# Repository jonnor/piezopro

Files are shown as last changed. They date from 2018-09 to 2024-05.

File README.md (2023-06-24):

Piezo module with integrated preamp in fully shielded package.

# Status
Developing first prototype

# TODO

Preamp Revision 2 testing

* Measure frequency response of amplifier with Bitscope
* Measure signal/noise ratio or noise floor.
* Test with 5V power supply
* Test overvoltage on connector. VGND,HOT,COLD

Preamp Revision 3

* Depending on test results
* Test a charge amplifier?
* Test a JFET directly on piezo?

Final revision

* Document test procedure for PCB and/or assembly.

## Questions

* PCB stackup retains piezo sensitivity.
Put piezo onto PCB. With glue? Use adhesive tape to attach to instrument.
Measure output level. Compare to without PCB. Compare to coppertape+covertape.
Maybe the bottom should just be piezo+coppertape, sides+top is PCB? Can still look "perfect" from outside.
* PCB stackup is a good way to shield.
Test having just a few (4) connected holes in mid layer (from top/bottom). Can noise get in? 50Hz
Emulate side-plated PCB using copper tape. How much does it improve?
* Frequency response should include resonant peak.
For 27mm element is as low as 4kHz, within fundamentals of piano. 12mm=9kHz. 9mm=18kHz, edge of human hearing.
How pronouced is this peak actually when mounted on instrument?

# Design test

Revision 1. gain. 220k/22k. 10M input.
20mm Murata. Piezo in tin, glued. Lying on top of guitar. 
Measured GND, HOT. on output.
low E string. 80mVpp sustained, 500mVpp attack
G string. 70mVpp sustained, 700mVpp attack
high E string. 70mVpp sustain, 800mVpp attack

Current consumption 0.68 mA.

## Learnings

* Basic circuit works. Both with balanced and unbalanced inputs.
* Using a tin box works well as a shield.
* With microphone level input, signal is too hot.

# Worklog

Rev1: Circuit design verification. 22 hours

* Sept 08. 4 hours. Research exiting designs, initial schematic.
* Sept 09. 4 hours. Part selection and initial layout.
* Sept 09. 1 / 4 hours. Setup simulation in KiCAD.
* Sept 14. 1 hour. Sketching piezo mounts with rim/center attach
* Sept 19. 7 hours. Assembly and testing revision 1 PCB.
* Sept 22. 2 hours. Test overvoltage, calculate new component values

Rev2: Assembly concept verification. 7 hours 

* Oct 4. 4 hours. Update schematic and layout for revision 2. 
* Oct 8. 3 hours. Go through revision 2.
* Oct 3. 1 / 4 hours. Find out how to import artwork in KiCAD

Rev3: Production tweaked

* March 16. 2 hours. Make Python tool for vias shielding, use instead of edge platings

# Requirements

Electronics

* PCB is an enclosure for 20mm piezo. 25mm outer diameter
* BOM max 3 USD
* 100 hours++ on 9V battery. Max 2mA avg draw
* Low noise
* Balanced output. But also works with unbalanced inputs
* Line-level output, +4dBU
* 20Hz-20kHz bandwidth
* Reverse polarity protection
* Input overvoltage protection

Mechanics

* Cylindrical
* Fully shielded
* Output: 1/4" TRS female
* Power: 9V battery clip
* 1m cable, soft/flexible

# Sourcing

* Capacitors.
[0.1uF](https://no.farnell.com/w/c/passive-components/capacitors/ceramic-capacitors/smd-ceramic-multilayer-mlcc-capacitors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|35v&range=inc-in-stock-grp1&sort=P_PRICE)
[10uF](https://no.farnell.com/w/c/passive-components/capacitors/ceramic-capacitors/smd-ceramic-multilayer-mlcc-capacitors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|10v|25v|35v&range=inc-in-stock-grp1&sort=P_PRICE)
* NMOS. [BSS138L](https://no.farnell.com/on-semiconductor/bss138lt1g/mosfet-n-50v-0-2a-sot-23/dp/1431319)
* Diodes [SOD-532](https://no.farnell.com/w/c/semiconductors-discretes/diodes/small-signal-diodes?diode-case-style=sod-523|sod-523f&no-of-pins=2pins|3pins&packaging=cuttape&range=inc-in-stock-grp1|exc-obs&sort=P_PRICE)
*  Zeners [SOD-523](https://no.farnell.com/w/c/semiconductors-discretes/diodes/zener-single-diodes?zener-voltage-vz-typ=3.3v|3.6v|3.9v|4.3v|4.7v|5.1v&diode-case-style=sod-523|sod-523f&no-of-pins=2pins|3pins&packaging=cuttape&range=inc-in-stock&sort=P_PRICE)
* Opamp. [TL062](https://no.farnell.com/search/prl/results?packaging=cuttape&range=inc-in-stock&st=tl062&sort=P_PRICE)
* Piezo [Farnell](https://no.farnell.com/w/c/sensors-transducers/transducers/sensing-transducers/piezo-transducer-elements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|35mm&range=inc-in-stock)

# BOM

[Octopart BOM](https://octopart.com/bom-tool/TbIQ2Cbo/OKDwL97yteywY4BA)

## Testing

Testing aspects

* PCB design verification
* Enclosure/mount design verification
* Production checks.

Tough-but-normal conditions

* 3-8 microphones
* Plugged into standard mixer with 50m cable
* 1 9V battery per microphone

Reverse polarity:
Hold battery on wrong way for 10 seconds, plug right way, ensure works OK.

Overvoltage:
Hit piezo with hammer. Ensure performance good afterwards.

Frequency response:
Connect signal generator at PCB input, with capacitor simulating piezo capacitance.
Sweep sinewave, record output, calculate frequency response.

Noise.
Internal noise. No signal. Measure output
Injected noise/interference (on output line, at microphone).
Attempt to inject 50Hz by wire. Lightbubl+dimmer.
Measure without shielding, and with.

## References

Electronics

* [Elliot Sound Products: Balanced Line Driver](http://sound.whsites.net/articles/dwopa3.htm#s10)
* [Elliot Sound Products: High-Z ](http://sound.whsites.net/articles/high-z.html)
* [WikiPedia: Line level](https://en.wikipedia.org/wiki/Line_level). Consumer: -10dBV 0.894 Vpp, Pro: +4dBu 3.472
* [StackExchange.com: Piezo FET preamp balanced output](https://sound.stackexchange.com/questions/687/diy-contact-microphone/37714#37714).
Developed by Alex Rice, www.zachpoff.com/diy-resources/alex-rice-piezo-preamplifier/.
Extremely simple design. Used as base for DIY kits and complete microphone Cortado MkII from Zeppelin Labs. 
* [Elliot Sound Products: Piezo Pickup Preamplifiers](https://sound-au.com/project202.htm).
Tested high-Z preamp versus Charge Amplifier.
First opamp stage is charge amp with 1x gain, then second stage sets desired gain.
Found that high-Z would pick up (50hz) hum, where as charge amplifier did not. When piezo was connected with bare leads.
Tested with TL072 and found it very quiet.

Shielding

* [Shielding fabric](https://www.aliexpress.com/item/Emf-shielding-Fabric-Signal-Block-Fabric-Military-Nickel-Fabric/32795159060.html)
* [Shielding paint](https://www.stewmac.com/Pickups_and_Electronics/Shielding/Conductive_Shielding_Paint.html)

Simulation

* [ngspice: Using KiCAD as GUI](http://ngspice.sourceforge.net/ngspice-eeschema.html)
* [eCircuitCenter: Basic SPICE opamp model](http://www.ecircuitcenter.com/Circuits/opmodel1/opmodel2.htm)
* [WikiPedia: Piezoelectric sensor](https://en.wikipedia.org/wiki/Piezoelectric_sensor).
Basic model (disregards resonance): Voltage source with a capacitor in series.

## Existing products

Active contact microphones

- Schertler. [Thommann](https://www.thomann.de/gb/schertler_dyn_uni_p48_contact_microphone.htm).
48V phantom power.
310 EUR.
- Cortado MkII [from Zeppelin Labs](https://zeppelindesignlabs.com/product/cortado-mkiii-contact-microphone/).
48V phantom power. Two gain settings, low-frequency cutoff switch.
150 USD assembled.
- K&K Pure pickup plus K&K Pure preamp. [Thommann](https://www.thomannmusic.no/kk_pure_preamp.htm?sid=fd268c89787f256dcc79b210d18a3667).
Total around 300 EUR

# Usage ideas

* Guitar. Acoustic, electric, traveller.
* DIY Cigarbox
* CNC mill an electric travel guitar from single piece of wood. Rosewood/maple.
https://www.aliexpress.com/item/Hot-Sale-Custom-Electric-Travel-Guitar-Portable-Style-Rosewood-Fretboard-22-Frets-with-Soft-Bag-can/32803999609.html
* Violin,viola,chello. 
* Double bass. 
* Stomp box

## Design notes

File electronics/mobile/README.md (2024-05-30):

# PiezoPro Mobile preamp

Designed for use with consumer electronics like mobile phone / PC.
And an off-the-shelf piezo module. Either from music store, China online, or using own piezo disc.

# Features

- 3.5 mm input jack for piezo
- 3.5 mm output jack. Line level
- Adjustable gain. 0 to 34 dB?
- Ability to switch on/off
- Rechargable battery. 100 hours + battery life
- USB-C charging port
- Shielded chassis

# Implementation

- Li-ion battery. Cell on JST style connector.
- CMOS opamp
- 3d-print casing. Copper tape for shielding?

# Background

## Opamp choice

CMOS opamps seems to be the way to go.
High impedance. Low power. Low noise. Good gain bandwidth product.

- TI OPA1671. 900 uA consumption
- TI OPA314. 150 uA consumption

## Battery types
Lithium polymer on JST connector.

- 602025, 200 mAh.
- 502035, 400 mAh

On-PCB.

- LIR2450, 100 mAh.

## References

### Metal Marshmellow Pro

Metal marshmellow Pro has 0-34 dB gain.
Has phantom power.

### Metal Marshmellow II

https://metalmarshmallow.com/MM_II.php

Has an internal battery. 10 days battery life. 240 hours.
Charging via micro USB. Charging time 1 hour.
Fixed gain. Multiple variants. From 0 to +34 dB. With +24 dB considered "normal" gain.
Seems to use a standard 20 ish mm piezo disc as the input element.

Says +14 dB is good for loud percussion.
And +24 dB for normal.
And +33 dB for very quiet sounds.

### Metal Marshmellow DIY

Can here see the circuit that is being used in the Pro.

Seems to be a single opamp. Markings are 1D3 ?
According to TI part lookup this could be OPA1671, a CMOS 

With 3-5.5 V range.
With input protection diodes etc.
DC output as well as AC coupled.
Can connect a pot-meter to pins, or fixed SMD resistor to set gain.

### Stompville

https://stompville.co.uk/cart/preamps

Seems to be based on a discrete JFET.
Has +14 dB gain.

Multiple versions. Unbalanced output PCB. Phantom power PCB.
Fully enclosed, alu chassis.

Prices around 50 GPD for PCB.

###

https://www.instructables.com/Hi-Z-Opamp-Piezo-Buffer/

P48 phantom power design, with balanced output.
OPA1642 based.
Has the schematic.
Modern SMD circuit board also available.
https://www.jlielectronics.com/diy-accessories/p48-hi-z-piezo-buffer/ - 35 USD.
Nice standard case in steel with XLR/6.35mm for keeping it in.

### JFET composite amplifier

JFE150 has a complete reference design for a JFET composite amplifier (JFET + single opamp).
With gain up to 60 dB.
Well described, in terms of component choices.

However, a standard CMOS/JFET opamp is probably good enough?
The JFE150 part is a bit exotic.

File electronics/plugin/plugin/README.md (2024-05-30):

# Plug-in-power

Contains a single JFET buffer, designed to be powered from "Plug in power" (PIP) at 3-5 volts.
Very similar to off-the-shelf electret microphone modules are done.
Can be directly plugged into a device with mic-level input supporting PIP.
Such as a portable recorder, PC, phone or laptop.
Or use preamps or adapters designed for electret microphones.

Board designed to be soldered directly to piezo element, using castellated edge holes.
The assembly should then protected mechanically using silicone etc,
and be shielded completely using copper tape.
And potentially coated with plastidip et.c. to be fully waterproof.
Output is a NN cm long cable with 3.5 mm TRRS male.

## TODO

- Adapt circuit to have trimpot for Rs
- Select and order components. Follow Zack Hoff PIP amp. JFET: 2SK209
- Make and test initial circuit
- Measure gain, noise levels

## Open questions

- Does this two-step amplified design work give good quality? First JFET buffer, then external preamp?
Test the circuit externally.
Test how copper shielding affects.
Over just the piezo. Over piezo, and PCB separate. Over piezo and PCB integrated.

- How is sound pickup influenced by mounting PCB onto the piezo?

Alternative fully-integrated design.
Put everything needed also for P48V phantom power and 9V.
Then just have different sets of wires coming out for different connectivity options.

## Challenges

Multiple usage scenarios with different expectations of connection

- Instrument. 9V battery + female jack
- XLR with phantom power
- Portable recorder. Plug-in-power. Though some also have XLR or TRS

Different usage scenarious may have different input level,
and require different gain

- Ambient listening. High sensitivity desired
- Stringed/plucked instruments. Guitar, kaliba, piano etc. Relatively loud
- Percussive instruments. Very loud / high energy

## Learnings

### Direct soldering

06.08.2023. Tested soldering a PCB board with castellated holes directly to a PCB.
Worked quite nicely. Heated the PCB castellated first, then feed solder on pad, then towards piezo.
Used 280 deg C soldering iron, was sufficient.

## Components

#### SMD JFET for audio

SOT23 DSG: Gate on tip

- 2SK3557 - SOT23 DSG
- MMBF4416A - SOT23 DSG
- MMBF5484/MMBF5485/MMBF5486 - SOT23 DSG. 5484 has lowest VGS_off - good
- MMBFJ309/MMBFJ310 - SOT23 DSG. 309 has lowest VGS_off - good
- MMBF4393LT1G - SOT23 DSG
- MMBFJ201 - SOT23 DSG.
- SST201 - SOT23. Low cutoff voltage
- LSBF510 - SOT23. Low cutoff voltage
- 2N4117

Very expensive

- sst310

Discontinued

- MMBF4393
- Philips bf512
- MMBF4416
- BF256B
- BF862
- BF556

Specialiy

- JFE150 SOT23-5. Modern. Includes clamping diodes

Electret Capsule Microphone (ECM) specialized

- 2SK208. SOT23. Pin order different? No proction diodes. Normally in stock Digikey.
- 2SK1109. SOT23. Comes with binning of IDDS. Obsolete? 
- TF256TH. One diode internally. Comes with binning of IDDS. SC-106A SMD. Obsolete?
- NTE2917. TO92S

Others by others with success

- 2SK209. By Zack Hoff

## References

### Zack Poff: PIP Stereo Piezo Preamplifier

https://www.zachpoff.com/resources/pip-stereo-piezo-preamplifier/

Very simple circuit.
JFET, Zeners for protection.
Mentions possibility of adding a capacitor on Rs to increase gain.
Used the 2SK209 SMD JFET (IDSS grade Y). After testing many others.
Zeners are back-to-back. 5.1V
Stereo. Two channels on single PCB.
Have to solder inputs and outputs to wires. No connectors.
3d-printed enclosure.
Has a "pad" switch. Pulls some capacitors to ground.
Says there is sufficient gain for quiet sources. But not the best for percussive. Presumably overloading output.

!! He has tested the spread of the JFETs.
They should be measured and binned by IDSS, for best results.

Excellent starting point for an inline PIP preamp.
Would instead use 3.5 mm female jacks. SMT, avoid soldering cable.
Also tweaking the enclosure and PCB to make shielding trivial. 
Copper foil/tape that connects to PCB. Solder one spot and then press-connect.
And order it pre-made at JLCPCB etc.

His preamp was used in combination with below DYI piezos.

### 3D-Printed DIY Contact Microphone

https://www.zachpoff.com/resources/3d-printed-diy-contact-microphone/
27mm piezo disk.
Glued to 1-1/8″ dia Aluminum discs. Approx 29 mm.
3D-printed back shells.
The alu disc makes them quite sturdy. Also also reduces the reasonant peak. At the expense of some sensitivity.
?? No shielding in the enclosure. Not mentioned the effect of this.
Tested by students over many years.

Seems like a very practical construction.

### Elliot Sound: JFET amplifier design
https://sound-au.com/articles/jfet-design.htm#s3

Most important JFET parameters:

- the gate-source cutoff voltage VGS (off). Aka  'pinch-off' voltage (VP).
- and the maximum current with zero gate voltage (IDSS).

Must in practice be measured.
Large amount of unit variation in these. 
Shows a practical test circuits to measure the key parameters.

Lots of discussion on how to set bias point (via selecting R_s).
Recommends a trim-pot for R_s.

The lower the supply voltage, the more accurate the biasing needs to be.

## Bias point and component selection

In this applicaion there will also be some external variation in R_s on,
so the circuit must be robust to a reasonable range of these.
Complicates testing of the bias point. 

In practice JFET selection is likely to be critical.
And it is quite likely that JFETs must be measured/binned.

=> this design is only ideal when direct operation as "elecret" mic is needed.
If an external power source is acceptable, then a op-amp based charge amplifier is better.

Gain adjustment has to be primarily done by selecting another JFET.
The other option is to use the resistive divider on the input,
but this reduces SNR. 

## Accessories

#### XLR converter

PIP 3.5mm TRS to XLR phantom power

- Rode VXLR+
https://www.thomann.de/be/rode_vxlr_416774.htm
- Movo FXLR-PRO 
- Boya 35C-XLR

#### Battery box

Ideally with jack socket (female).
For guitar amp etc connection.

Not so much completely ready??

- MC-401 condenser mic mixer. 4 in, 1 out
- MC33202 Dynamic Condenser Microphone Preamplifier. 1 elecret input 
- Soundman A3 adapter?
- Soundprofessionsals SP-SPSB-1
https://soundprofessionals.com/product-category/microphone-power-modules-battery-modules/

There are a bunch of ready-made electret amplifier boards

- 3V/5V/12V Input MAX9812 Electret Microphone Amplifier
- LM358

Would need to add minijack input, jack output, and 9V battery connector.

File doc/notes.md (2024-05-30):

Make into piezo preamplifier board.
Allowing use of any piezo.
Source some decent piezo elements that is tested together.
Provide as a kit.

Externals. Connectors etc

- Piezo input. 3.5 mm audio jack
- Audio output. 3.5 mm audio jack.
- Power. 5.5 mm DC jack
- Gain. 2/3 way switchable button
- LED power indicator
- Power switch?

Accessories:

- 3.5 mm jack to XLR 
- DC jack to 9V battery
- 3.5 mm stereo extension cord

Physical characteristics

- Like an 9V battery. 50 mm x 30 mm x 15
- In-line connections.
Input connector on one side, output connectors other side
- Preferably a way to attach with screws?

DC 5.5 OD socket is 11 mm tall above PCB. Min 15mm tall
3.5 mm audio jack is 12m diameter
DC 5.5 OD jack is 10 mm diameter

PP3 size battery is 48.5 mm × 26.5 mm × 17.5 mm
XLR connector is 70 mm x 19 mm diameter

## Audio connector
https://www.digikey.com/en/products/filter/barrel-audio-connectors/434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

## Power connector
https://www.digikey.com/en/products/filter/barrel-power-connectors/435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

## Switches
https://www.digikey.com/en/products/filter/slide-switches/213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

# Existing

Guitar piezo/ceramic preamp/amplifiers

## EQ-7545R

Approx 7 USD from China
Belcat branded 25 USD
4 band EQ and volume control.
For building into guitar
9V battery holder
2.5mm female socket internal for piezo input
6.35 mm female socket for audio output

https://www.gear4music.no/no/Gitar-and-Bass/Belcat-EQ-7545-4-bands-Aktiv-Preamp/AV8

## Radial Stagebug SB-4
DI box for piezo
1000 NOK
48 V phantom power
https://www.gear4music.no/no/PA-DJ-and-belysning/Radial-StageBug-SB-4-Active-Piezo-DI-Box/V6S

Provides full specifications
Tilsvarende inngangsstøy: -101dBu
Støy gulv: -97dBu 

## Casing

Light enough to work with double sided tape
Optional mounting bracket

Can easily become the most expensive part
Should be rugged enough to have good price
Stock plastic with cutouts?
Aluminum (or plastic) profile with custom sides

https://www.hammfg.com/electronics/small-case/extruded/1455
might be hard to find small enough
want ideally 5 mm tall

G2AA DIY Aluminum Case Electronic Project PCB Instrument Box 45x45x18.5mm
23x44x60mm PCB Junction Box Metal Aluminum Cooling Box DIY

3d-printed?
Could one use texturing etc to make it look good?

https://www.romanreiner.com/creating-textures-for-3d-printing/
Texturing using displacement map
https://grabcad.com/tutorials/how-to-3d-texture-your-parts-for-fdm-printing-using-solidworks-2019
https://www.cati.com/blog/2019/06/how-to-quickly-add-texture-to-fdm-3d-prints-in-solidworks/
Triangular
Bowtie
Can be done in Blender?

If the part is small and flat enough, maybe just a sticker on top will make it look OK

Can one make the price good

## Usecases

- Drums/percussion
- Guitar. Acoustic/electric
- Violin

## Output

Ready to be used with

- Guitar amplifier
"instrument level"
Like an Active DI box.
- Phone/tablet/computer
Using the microphone input
Will need a 9V battery
- XLR audio interface
Either a mixer or USB audio soundcard
"mic level"

## Distributors

- Thomann
- Gear4music

## Configuration

- Power input source
Between phantom and 
Maybe auto-switch instead?
Prefer phantom power where present

- Gain / output level.
Some instruments might be very loud
Some piezos might be very loud
Continiously adjustable. Potmeter
Or couple of steps. 10,20db pad

- High pass filter
Need to avoid handling noise etc
Can be a lot of energy in the low-end
Maybe a switchable filter
Generally better to use an EQ

- Low pass filter
Not so important where it is
Better to use an EQ

# Testing method

## Real-world test
Place on some instrument.
Compare with other piezos.

On acoustic guitar.

## Measurements wrt reference

Need a reference equipment with known response.
Either linear or just well specified

Probably not so important in practice

## Main characteristics

- Signal to Noise ratio
Higher signal level usually beneficial.
Since there is also input noise
- Frequency response
Want low freq dropoff to avoid/reduce handling noise
High dropoff outside hearable range
- Distortion

- Softstart. No pop on power on/off

## Piezo resonance

Piezos have natural resonances.
Depends primarily on size of element
The height of peak proably also depends on material around piezo, and how it is mounted
Some manufacturers specify it
Might

# References

## Line levels

https://www.plaiddogrecording.com/lesson-2

Line-level. Balanced or unbalanced compatible.

    Microphone Level = -58 dBu to +2.2 dBu = 1 millivolt to 1 volt
    Instrument Level = -17.7 dBu to +7 dBu = .1 volt to 1.736 volts
    Line Level = -4.8 dBu to +4 dBu = .447 volts to 1.228 volts
    Speaker Level = +7 dBu to +30 dBu and above = 1.736 volts to 24.5+ volts

While the values for these levels can vary and overlap quite a bit, the average levels (references) are around here:

    Mic Level = -30 dBu = 24 mV
    Instrument Level = 0 dBu = .775 V
    Line Level = +4 dBu = 1.228 V
    Speaker Level = +14.26 dBu = 4 V

Instrument level and line level nearly the same.
Mic level considerably different.

Can typical XLR mic preamps handle instrument or line level?

Behringer Xenix. Max level +10 dBu, yes

## Piezo levels

What are the levels the piezo produces under the range of usecases?

NOTE: may depend the buffer being used.
Baseline: JFET unity-gain opamp

Instrument usage

- Guitar. Electric vs acoustic. Soft vs hard playing. High vs low strings.
- Kalimba. Soft vs hard playing
- Drums. Electronic pad
- Piano.

Sound installation

- Bridge with someone walking on it
 Or just the

Overload conditions

- Drop piezo on floor
- Hit with finger
- Hit with hammer

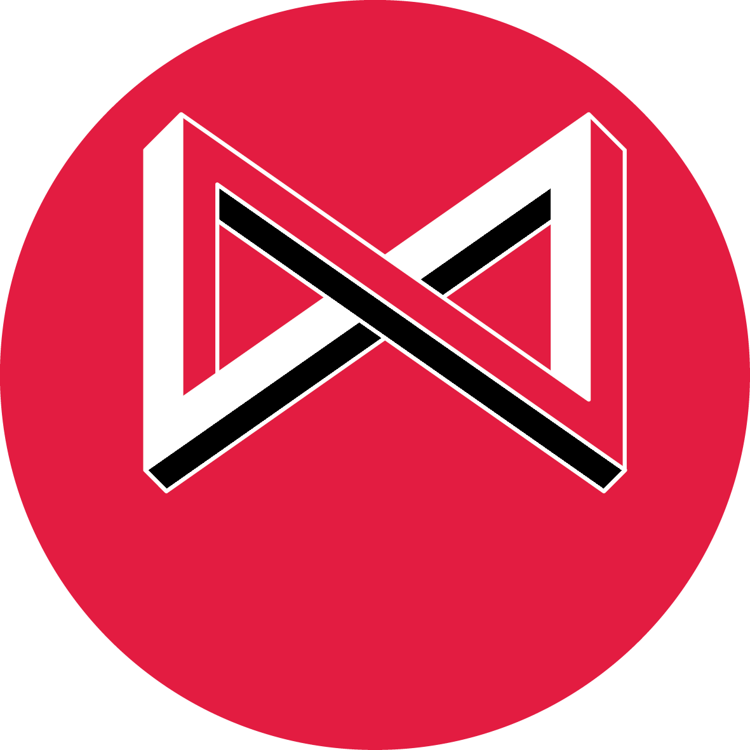
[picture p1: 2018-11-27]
electronics/preamp/artwork-midres-contrast.png

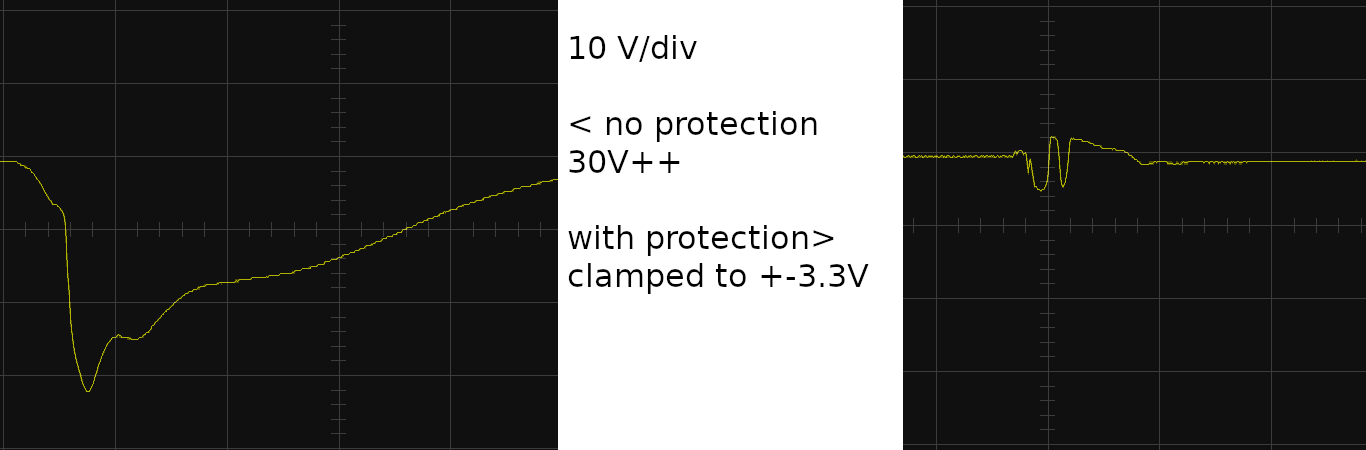
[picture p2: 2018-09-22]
doc/img/overvolt-protect-murata-20.png

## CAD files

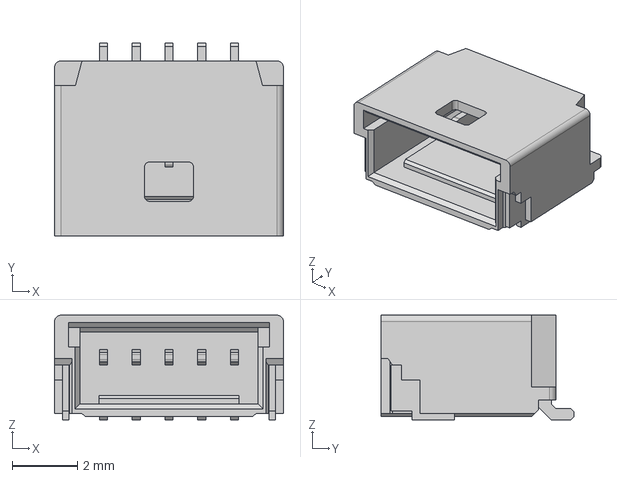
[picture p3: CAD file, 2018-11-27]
electronics/MOLEX Pico-Clasp 5-xy.step
7.00 x 5.90 x 3.20 mm

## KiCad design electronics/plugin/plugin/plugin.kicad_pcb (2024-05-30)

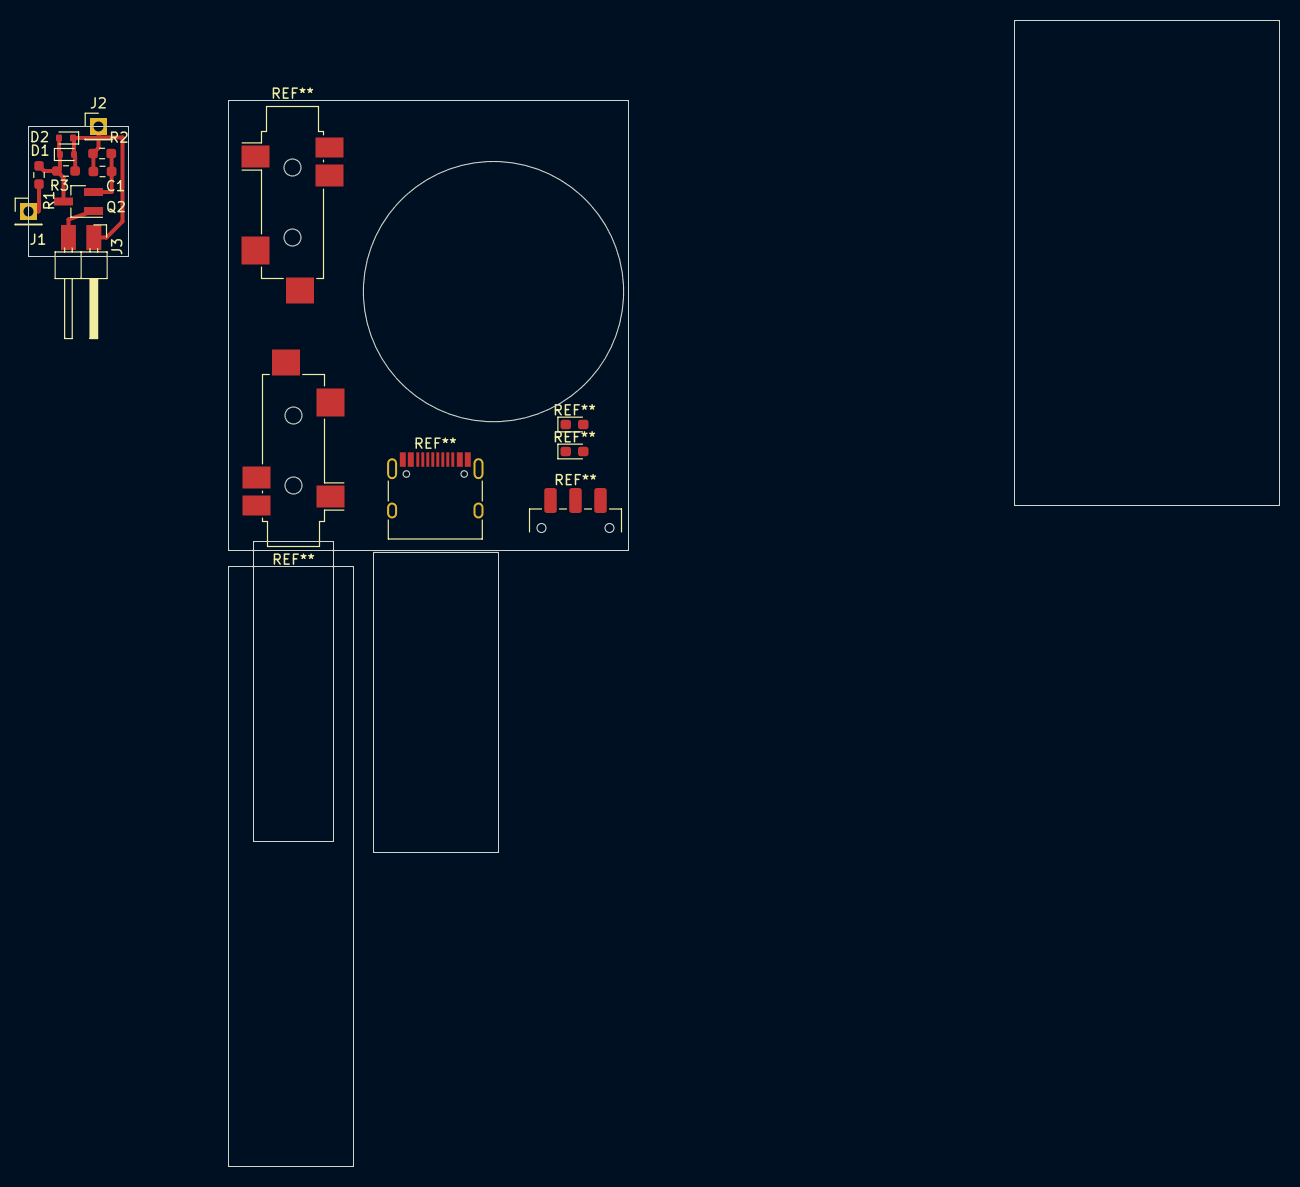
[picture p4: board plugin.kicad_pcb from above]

Board: 2 copper layers, 125.1 x 114.6 mm, 10 parts (0 on the bottom side), 5 nets.

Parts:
C1: C; R_0603_1608Metric_Pad0.98x0.95mm_HandSolder
D1, D2: D; D_SOD-523
J1, J2: Conn_01x01; PinHeader_1x01_P2.54mm_Vertical
J3: Conn_01x02; PinHeader_1x02_P2.54mm_Horizontal
Q2: Q_NMOS_DSG; SOT-23_Handsoldering
R1: 100; R_0603_1608Metric_Pad0.98x0.95mm_HandSolder
R2: R; R_0603_1608Metric_Pad0.98x0.95mm_HandSolder
R3: 1M; R_0603_1608Metric_Pad0.98x0.95mm_HandSolder

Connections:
/GATE: D1.1 (K), D2.2 (A), Q2.3 (G), R1.2, R3.1
/OUT: J3.2, Q2.1 (D)
GND: C1.2, D1.2 (A), D2.1 (K), J2.1, J3.1, R2.2, R3.2
unnamed: J1.1, R1.1
unnamed: C1.1, Q2.2 (S), R2.1

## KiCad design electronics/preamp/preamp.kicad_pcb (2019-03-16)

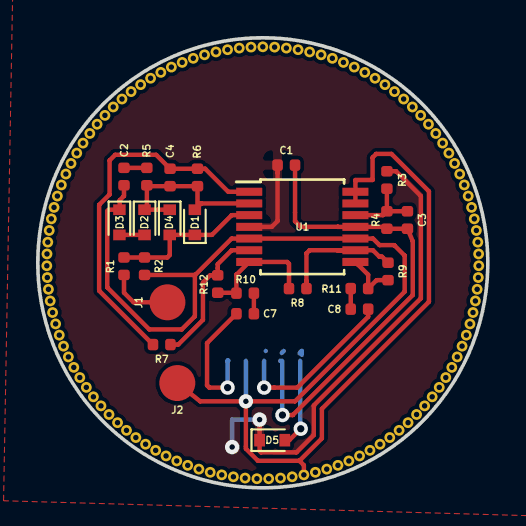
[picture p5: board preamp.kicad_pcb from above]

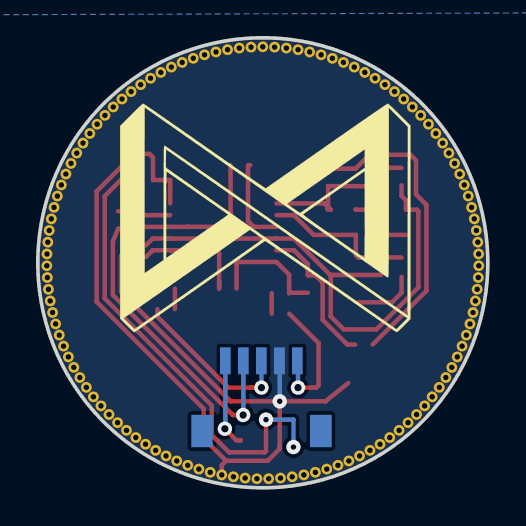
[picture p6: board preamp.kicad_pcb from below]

Board: 2 copper layers, 25.0 x 25.0 mm, 28 parts (2 on the bottom side), 19 nets.

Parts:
C1, C3: 0.1uF 15V; C_0402_1005Metric
C2: 1uF; C_0402_1005Metric
C4: 1000pF; C_0402_1005Metric
C7, C8: 10uF; C_0402_1005Metric
D1, D4, D5: D; D_SOD-523
D2, D3: Zener 3V1; D_SOD-523
J1, J2: Conn_01x01; TestPoint_THTPad_1.0x1.0mm_Drill0.5mm
J3: Conn_01x05; Molex_Pico-Clasp_202396-0507_1x05-1MP_P1.00mm_Horizontal_No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
J4: Conn_01x01; viashield
R1, R3, R4, R5, R6, R7: 12k; R_0402_1005Metric
R2: 10M; R_0402_1005Metric
R8, R9: 100k 1%; R_0402_1005Metric
R10, R11: 100 1%; R_0402_1005Metric
R12: 27k; R_0402_1005Metric
U1: TL064; TSSOP-14_4.4x5mm_P0.65mm

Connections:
+BATT: D5.2, J3.1
-BATT: C1.2, C3.2, J3.2, R4.2, U1.11
/AMP: C4.2, R6.1, R7.2, U1.1
/BUF+: R8.2, R10.2, R12.1, U1.7
/BUF-: R9.1, R11.2, U1.8
/GAIN-: R7.1, R12.2, U1.6
/IN+: J1.1, R1.2
/INV-: R8.1, R9.2, U1.9
/OUT+: C7.1, J3.5
/OUT-: C8.1, J3.3
/PRE+: D1.1, D4.2, R1.1, R2.2, U1.3
/PRE-: C4.1, D1.2, D2.1, D4.1, R5.2, R6.2, U1.2
/VGNDREF: C3.1, R3.2, R4.1, U1.12
unnamed: C2.1, R5.1
unnamed: C7.2, R10.1
unnamed: C8.2, R11.1
unnamed: D2.2, D3.2
VCC: C1.1, D5.1, R3.1, U1.4
VGND: C2.2, D3.1, J2.1, J3.4, J4.1, R2.1, U1.5, U1.10, U1.13, U1.14

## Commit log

2018-09-08 Initial schematic
    [preamp.kicad_pcb, preamp.sch]
2018-09-09 Add reverse polarity protect
    [preamp.sch]
2018-09-09 Output caps, fix opamp annotations
    [preamp.sch]
2018-09-09 Initial layout concept
    [preamp.kicad_pcb, preamp.sch]
2018-09-09 Tweak component placement
    [preamp.kicad_pcb, preamp.sch]
2018-09-09 Simulation was performed, tweak some values
    [preamp.sch]
2018-09-09 Initial routing
    [preamp.kicad_pcb, preamp.sch]
2018-09-09 Tweak routing a little bit
    [preamp.kicad_pcb]
2018-09-09 Ready to make first proto
    [preamp.kicad_pcb]
2018-09-15 Add production files for revision 1
    [preamp-B.Cu.gbl, preamp-B.Mask.gbs, preamp-B.Paste.gbp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]
2018-09-15 Change to 100 ohm on input
    [preamp.kicad_pcb, preamp.sch]
2018-09-20 More useful label positions for placing components
    [preamp.kicad_pcb]
2018-10-04 preamp: Rev2 started
    [preamp.kicad_pcb, preamp.sch]
2018-10-04 preamp: Updated layout
    [preamp.kicad_pcb]
2018-10-04 preamp: Tweaks for BOM
    [preamp.kicad_pcb, preamp.sch]
2018-10-04 preamp: Tweak
    [preamp.kicad_pcb]
2018-10-04 phantomxlr: Basic circuit idea
    [phantomxlr.kicad_pcb, phantomxlr.sch]
2018-10-08 preamp: Tweak layout
    [preamp.kicad_pcb]
2018-10-08 preamp: Cleanup layout a bit
    [preamp.kicad_pcb]
2018-10-18 preamp: Add artwork
    - Import PNG into bitmap2component
    - Adjust tresholds to export mask and silkscreen
    - Merge the two files into one kicad_mod
    - Import the footprint, flip to back and rotate
    [preamp.kicad_pcb]
2018-10-18 preamp: Add edge plating connector
    [preamp.kicad_pcb]
2018-11-27 preamp: Import highres artwork
    [preamp.kicad_pcb]
2018-11-27 preamp: Add 3d-model of connector
    [MOLEX Pico-Clasp 5-xy.step, preamp.kicad_pcb]
2018-11-27 Fix artwork being wrong size
    [preamp.kicad_pcb]
2019-01-28 preamp: Move via under connector
    [preamp.kicad_pcb]
2019-01-28 preamp: Update copper fills
    [preamp.kicad_pcb]
2019-03-16 Compress and prettify traces
    [preamp.kicad_pcb]
2019-03-16 preamp: Use via shield
    [preamp.kicad_pcb, preamp.sch]
2019-03-16 preamp: Move last via underneath connector
    [preamp.kicad_pcb]
2023-06-24 plugin: Add new preamp concept
    [plugin.kicad_pcb, plugin.kicad_sch]
2023-08-06 plugin: Fix protection, notes on solder test and JFET amp setup
    [plugin.kicad_pcb, plugin.kicad_sch]
2024-05-30 Add some notes on PIP and a separate battery-powered preamp
    [plugin.kicad_pcb, plugin.kicad_sch]
